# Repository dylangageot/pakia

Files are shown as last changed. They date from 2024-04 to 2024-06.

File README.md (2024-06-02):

# PS/2 to Amiga Keyboard Interface Adapter (PAKIA)

Standalone Amiga keyboards are more than ever difficult to find, especially due to the increased perceived value of Amiga computers and peripherals on the second-hand market.

Unfortunately, the keyboard interface used by Commodore is proprietary, see the [Amiga keyboard interface documentation](http://amigadev.elowar.com/read/ADCD_2.1/Hardware_Manual_guide/node0172.html).
Even though it uses the same 5-pin DIN 41524 connector as IBM AT keyboards, the keyboard interface is still different and therefore not compatible with any easy-to-find PC-compatible keyboards.

PAKIA is yet another adapter circuit, taking a PS/2 keyboard interface in input, and translating it into the Amiga keyboard interface in output.

<p align="center">
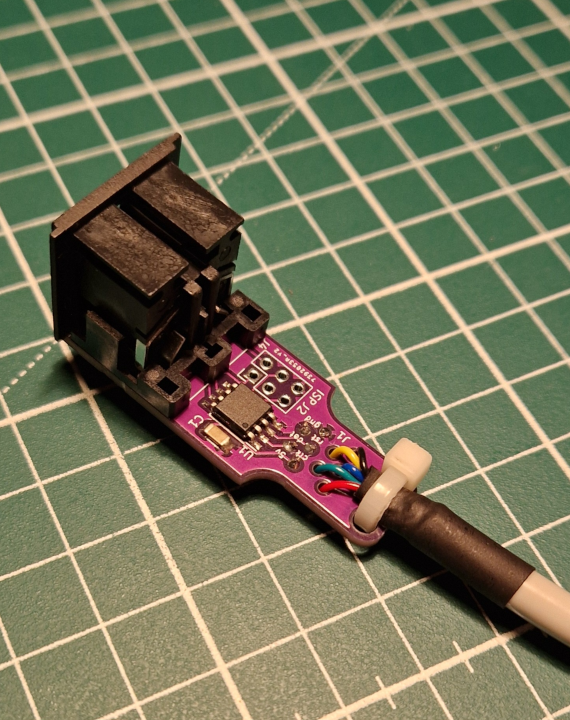
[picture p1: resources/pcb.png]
  
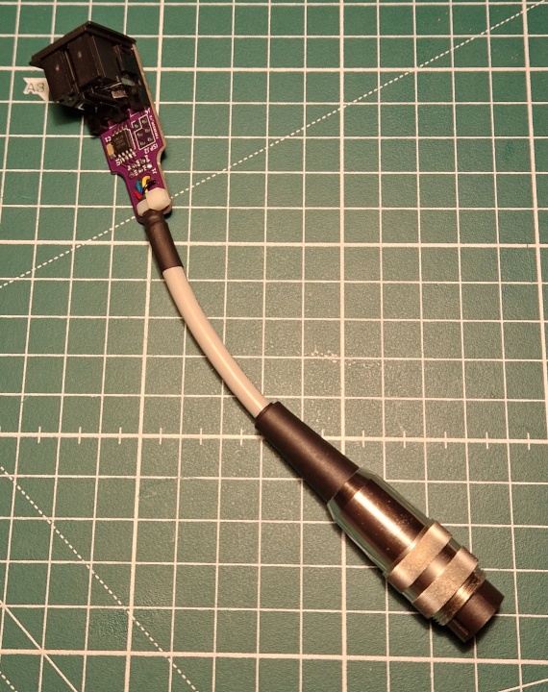
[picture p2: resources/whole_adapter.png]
  
</p>

## Features

- Convert PS/2 scancode to Amiga scancode,
- Handle lost synchronization and corresponding recovery,
- Handle the reset combo (Ctrl + Left Amiga + Right Amiga) with the two reset warnings,
- Interact with PS/2 keyboard to set Caps Lock LED,
- Use the [Menu](https://en.wikipedia.org/wiki/Menu_key) modifier key to type a key that has been absorbed by a larger key on the PS/2 keyboard but is present on an Amiga keyboard,
- PCB with: 
    - on-board DIN socket for AT and PS/2 keyboards connection, with the later usable with a mini-DIN to DIN adapter cable,
    - strain relief for wire coming from the Amiga. 

## Under the hood

Despite being different, both PS/2 and Amiga keyboard interfaces share similarities: they use the same KDAT and KCLK signal pair.
In either case, the keyboard is responsible for generating the clock and preparing 8 data bits to be read on the KDAT signal a falling or rising edge of the KCLK signal.

Leveraging multiple timers and interrupt service routines, an ATtiny85 captures frames sent out from an input PS/2 keyboard, interprets them, and then converts them to the Amiga keyboard interface using a look-up table written in Flash memory.

In contrast to other solutions, signal timings for the Amiga keyboard interface are driven by discrete time events instead of being driven by blocking delays.
One hardware timer generates periodic interrupt requests that once the corresponding ISR runs, the signal is taught to evolve its state through a software-based finite state machine, hence changing pins levels for both KDAT and KCLK.

This asynchronous philosophy makes it possible to incorporate this piece of software in a busier system, without introducing blocking delay when Amiga commands are being sent, minus interrupt service routines execution time of course.

You might think that this is overengineering and that other solutions got it right enough by using blocking delays to handle their signal timings, and you are probably right!
The solution I have implemented was way more stimulating for me to develop, so here we are!

The binary currently weighs 3.2KB, in that regard, one could choose to use an ATtiny45 instead of an ATtiny85, it might be enough even in case of additional features coming in future updates.

The project uses C++ mainly to benefit from namespaces.

## Build and deploy

> [!WARNING]
> The build system is only available on Linux.

> **Required:** `avr-gcc` and `avrdude`, respectively 5.4.0 and 6.3-20171130 on my setup.

1. Specify the programmer to use with `avrdude` in the Makefile, with the variable `PROGRAMMER`,
2. Build with `make`,
3. Deploy with `make flash` while your programmer is wired to the ISP connector on the PCB.

## Edit the translation map

The lookup table to convert PS/2 scancode to Amiga ones is hard-coded in `src/translation_map.hh`.
A tool called `translation-map-generator` can be built from the `tools` directory.
By modifying the source code, one can generate other hard-coded LUT from a readable code:

```bash
(cd tools && make)
tools/translation-map-generator > src/translation_map.hh
```

##  Schematic and PCB

The schematic and PCB were drawn in KiCAD. The project is available in the `hardware` directory.

## Other solutions

> "yet another adapter circuit", is there are other adapter circuits?

Yes, there are other adapter circuits! 

I have started this project blindly, without searching if anyone made one before.
Frankly, it was appealing to my eye, so why not!
I have found documentation on both keyboard interfaces and started developing a proof of concept on an Arduino Uno board, based on an ATmega328p.

I have discovered many of them once I had finished the prototype for PAKIA and wanted to design a PCB for it, with eventually a lighter microcontroller than the ATmega328p.
Here is a list of related open-source projects and their respective solutions:

- [AKAB](https://gitlab.com/hkzlab-retrocomputing/AKAB_Reloaded) by [hkzlabnet](http://mercatopo-en.blogspot.com/)
    - uses an ATmega328p as a microcontroller (32KB Flash, 2KB SRAM),
    - leverages a pure AVR development environment,
    - provides a KiCAD project with schematic and PCB design,
    - PCB based on both through-hole DIP-28 ATmega328p and mini-DIN socket,
    - see a photo of the adapter board in [the dedicated blog article](http://mercatopo-en.blogspot.com/2013/11/first-prototype-of-akab-amiga-keyboard.html),
    - implements Amiga Ctrl-Amiga-Amiga reset combo keys, 
- [PS2toAmiga](https://github.com/Jartza/PS2toAmiga) by [Jartza](https://github.com/Jartza)
    - uses an ATtiny85 as a microcontroller (8K Flash, 512B SRAM),
    - leverages the Arduino development environment,
    - provides a KiCAD project with schematic and PCB design,
    - PCB based on SMD SOIC8 ATtiny85 and pads to solder wires on for both PS/2 and Amiga keyboard wires,
    - designed to fit inside a keyboard,
    - see photos of the adapter board on the repository README.md,
    - implements Amiga Ctrl-Amiga-Amiga reset combo keys, 
    - two different keyboard layouts selectable from the *Scroll Lock* key.

There is also the [Lyra 3](http://wiki.icomp.de/wiki/Lyra_3) adapter sold by Individual Computers.
This one is very complete feature-wise, but I did not want to buy one as I thought that it would spoil my pleasure of developing my own, I'm sure you get it, right?

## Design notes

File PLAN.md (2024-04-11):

# Plan

***Resources:***
- [Arduino pinout](https://docs.arduino.cc/resources/pinouts/A000066-full-pinout.pdf)

# 1. Implement IBM AT PS/2 protocol

> The PS/2 keyboard port is electrically and logically identical to the IBM AT keyboard port, differing only in the type of electrical connector used. - [Wikipedia](https://en.wikipedia.org/wiki/PS/2_port)

The nature of the protocol is synchronous master/slave bidirectional, with favor from the keyboard to the host.
Data and clock signals are both open-collector controlled on each side.
The keyboard generates the clock signal, even when the host is sending data to the device.
The host controls the directions by pulling the clock line to LOW.
When the clock is set to LOW from the host, the keyboard is inhibited.
The keyboard should be able to see that and will stop transmitting data.

***Pinout of female DIN 5-pin:***
```
     .---. .---.
    /    |_|    \
   /             \    1: Clock
  | 3           1 |   2: Data
  | o  5     4  o |   3: Reset(XT Type-1)
   \  o   2   o  /    4: GND
    \     o     /     5: 5V
     `--.___,--'
```

***Sources:***
- https://github.com/tmk/tmk_keyboard/wiki/IBM-PC-AT-Keyboard-Protocol
- https://en.wikipedia.org/wiki/PS/2_port

## Implementation ideas

- Use interrupt on clock line to receive data
- When the clock is being controlled by the keyboard, use the corresponding pin in input mode
- When the clock has to be pulled to the low state by the host, use the corresponding pin in output with LOW state

## Todo

- ✅ First research on IBM protocol
- ✅ Cut the wire in half, solder sub-wires to the female DIN connector
- ✅ Solder HE14 header pin on the other side
- ✅ Acquire through an interrupt scan code from the keyboard
- ⬛ Communicate with the keyboard (set Num Lock, Caps Lock...)

## Correspondance scan code set 2

```
        ,-----------------------------------------------.
        |F13|F14|F15|F16|F17|F18|F19|F20|F21|F22|F23|F24|
,---.   |-----------------------------------------------|     ,-----------.     ,-----------.
|Esc|   |F1 |F2 |F3 |F4 |F5 |F6 |F7 |F8 |F9 |F10|F11|F12|     |PrS|ScL|Pau|     |VDn|VUp|Mut|
`---'   `-----------------------------------------------'     `-----------'     `-----------'
,-----------------------------------------------------------. ,-----------. ,---------------.
|  `|  1|  2|  3|  4|  5|  6|  7|  8|  9|  0|  -|  =|JPY|Bsp| |Ins|Hom|PgU| |NmL|  /|  *|  -|
|-----------------------------------------------------------| |-----------| |---------------|
|Tab  |  Q|  W|  E|  R|  T|  Y|  U|  I|  O|  P|  [|  ]|  \  | |Del|End|PgD| |  7|  8|  9|  +|
|-----------------------------------------------------------| `-----------' |---------------|
|CapsL |  A|  S|  D|  F|  G|  H|  J|  K|  L|  ;|  '|  #|Entr|               |  4|  5|  6|KP,|
|-----------------------------------------------------------|     ,---.     |---------------|
|Shft|  <|  Z|  X|  C|  V|  B|  N|  M|  ,|  .|  /| RO|Shift |     |Up |     |  1|  2|  3|Ent|
|-----------------------------------------------------------| ,-----------. |---------------|
|Ctl|Gui|Alt|MHEN|     Space      |HENK|KANA|Alt|Gui|App|Ctl| |Lef|Dow|Rig| |  #|  0|  .|KP=|
`-----------------------------------------------------------' `-----------' `---------------'

        ,-----------------------------------------------.
        | 08| 10| 18| 20| 28| 30| 38| 40| 48| 50| 57| 5F|
,---.   |-----------------------------------------------|     ,-----------.     ,-----------.
| 76|   | 05| 06| 04| 0C| 03| 0B| 83| 0A| 01| 09| 78| 07|     |+7C| 7E|+77|     |*21|*32|*23|
`---'   `-----------------------------------------------'     `-----------'     `-----------'
,-----------------------------------------------------------. ,-----------. ,---------------.
| 0E| 16| 1E| 26| 25| 2E| 36| 3D| 3E| 46| 45| 4E| 55| 6A| 66| |*70|*6C|*7D| | 77|*4A| 7C| 7B|
|-----------------------------------------------------------| |-----------| |---------------|
| 0D  | 15| 1D| 24| 2D| 2C| 35| 3C| 43| 44| 4D| 54| 5B|  5D | |*71|*69|*7A| | 6C| 75| 7D| 79|
|-----------------------------------------------------------| `-----------' |---------------|
| 58   | 1C| 1B| 23| 2B| 34| 33| 3B| 42| 4B| 4C| 52|^5D| 5A |               | 6B| 73| 74| 6D|
|-----------------------------------------------------------|     ,---.     |---------------|
| 12 | 61| 1A| 22| 21| 2A| 32| 31| 3A| 41| 49| 4A| 51|  59  |     |*75|     | 69| 72| 7A|*5A|
|-----------------------------------------------------------| ,-----------. |---------------|
| 14|*1F| 11| 67 |     29         | 64 | 13 |*11|*27|*2F|*14| |*6B|*72|*74| | 68| 70| 71| 63|
`-----------------------------------------------------------' `-----------' `---------------'
*: E0-prefixed codes
+7C: E0 12 E0 7C
+77: E1 14 77 E1 F0 14 F0 77
^: ISO hash key uses identical scancode 5D to US backslash.
51, 63, 68, 6A, 6D: Hidden keys in IBM model M [6]
```

# 2. Implement Amiga keyboard protocol

KCLK is managed by keyboard.
KDATA is managed by both.
Active low signal levels.
Open collector setup.

***Sources:***
- http://amigadev.elowar.com/read/ADCD_2.1/Hardware_Manual_guide/node0172.html

## Implementation idea

- Generate a discrete periodic interrupt by using a timer [Clear Time on Capture Match](https://ww1.microchip.com/downloads/en/DeviceDoc/Atmel-7810-Automotive-Microcontrollers-ATmega328P_Datasheet.pdf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) feature, powering the bit-banging timing for the Amiga protocol.
Wait for acknowledgment from the Amiga by setting up an interrupt on the falling or rising edge of the KDATA line.

## Todo

- ✅ Use timer and interrupt to implement CLOCK and DATA positioning for Amiga protocol
- ✅ Handle ACK from device on keyboard side (Arduino)
- ✅ Translate scancode to Amiga scancodes
- ✅ Move to PCINT for ack detection
- ✅ Find an appropriate MCU for the final product
        - does using a PCINT instead of INT0 for Amiga ack detection would suffice?
         in this case, we could use a cool ATTiny!
         ATTiny85 seems low on SRAM...
- ✅ Make a PCB
- ⬛ Design revision 2 using a dedicated DIN socket on the PCB, 
        - ✅ Add footprint for DIN 5PIN
        - ⬛ Add pad for wire soldering of amiga cable without hole
        - ⬛ Add dedicated ISP AVR socket
        - ⬛ Make hole for a 3D model case

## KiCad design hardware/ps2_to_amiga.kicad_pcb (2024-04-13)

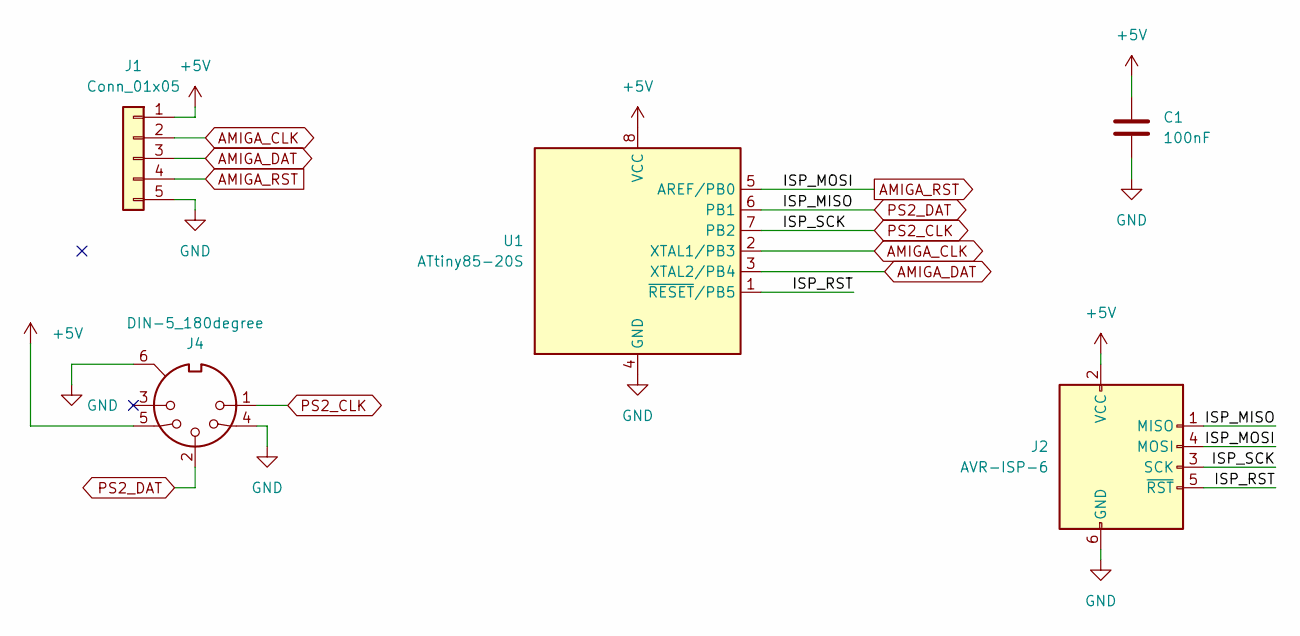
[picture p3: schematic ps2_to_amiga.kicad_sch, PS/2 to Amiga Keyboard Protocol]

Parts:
C1: 100nF; C_1206_3216Metric_Pad1.33x1.80mm_HandSolder
J1: Conn_01x05; AMIGA_KB_PADS
J2: AVR-ISP-6; PinHeader_2x03_P2.54mm_Vertical
J4: DIN-5_180degree; DIN_5PIN_180d_Female
U1: ATtiny85-20S; SOIC-8W_5.3x5.3mm_P1.27mm

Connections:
+5V: C1.1, J1.1, J2.2 (VCC), J4.5, U1.8 (VCC)
/ISP_RST: J2.5 (~RST), U1.1 (~RESET/PB5)
AMIGA_CLK: J1.2, U1.2 (XTAL1/PB3)
AMIGA_DAT: J1.3, U1.3 (XTAL2/PB4)
AMIGA_RST: J1.4, J2.4 (MOSI), U1.5 (AREF/PB0)
GND: C1.2, J1.5, J2.6 (GND), J4.4, J4.6, U1.4 (GND)
PS2_CLK: J2.3 (SCK), J4.1, U1.7 (PB2)
PS2_DAT: J2.1 (MISO), J4.2, U1.6 (PB1)

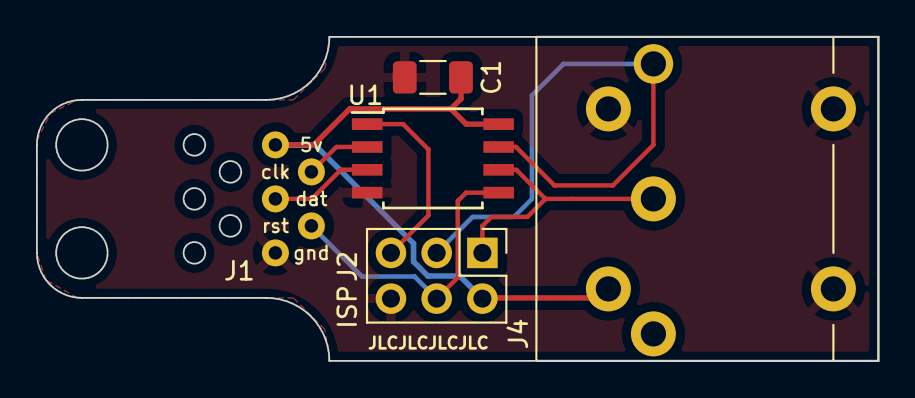
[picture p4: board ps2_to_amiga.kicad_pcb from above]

Board: 2 copper layers, 46.8 x 18.0 mm, 5 parts (0 on the bottom side), 8 nets.

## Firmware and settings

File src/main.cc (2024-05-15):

#include <avr/interrupt.h>
#include <avr/io.h>
#include <avr/wdt.h>

#include "amiga.hh"
#include "ps2.hh"
#include "scancodes.hh"
#include "translation_map.hh"

enum {
    COMBO_PRESSED = 7,
    RESET_REQUEST_SENT = 1 << 3,
    COMBO_RELEASED = 1 << 4
};

void setup() {
    MCUCR &= ~(1 << PUD);  // Enable pull-up resistors.
    MCUSR &= ~(1 << WDRF); // Reset Watchdog reset flag.
    wdt_disable();
    sei();
    ps2::begin();
    amiga::begin();
    ps2::send(ps2::command::RESET);
}

int main() {
    namespace scps2 = scancodes::ps2;
    namespace scami = scancodes::amiga;
    ps2::receiver receiver;
    ps2::event event;
    uint8_t last_scancode = 0;
    uint8_t reset_combo = 0;
    bool caps_lock = false;
    bool alt_num_pad = false;
    setup();
    while (1) {
        if (receiver.consume(event)) {
            uint8_t reset_key =
                (event.scancode == scps2::LEFT_CTRL ? 1 : 0) |
                (event.scancode == scps2::extended::LEFT_OS ? 2 : 0) |
                (event.scancode == scps2::extended::RIGHT_OS ? 4 : 0);

            // Detect reset combo (Ctrl + Left Amiga + Right Amiga).
            if (reset_key && !(reset_combo & COMBO_RELEASED)) {
                if (event.kind == ps2::event::PRESSED &&
                    !(reset_combo & RESET_REQUEST_SENT)) {
                    reset_combo |= reset_key;
                    if ((reset_combo & COMBO_PRESSED) == COMBO_PRESSED) {
                        amiga::hold_reset();
                        reset_combo |= RESET_REQUEST_SENT;
                    }
                } else if (event.kind == ps2::event::RELEASED) {
                    reset_combo &= ~reset_key;
                    if (reset_combo & RESET_REQUEST_SENT) {
                        amiga::release_reset();
                        reset_combo |= COMBO_RELEASED;
                    }
                }
            }

            if (amiga::is_ready()) {
                uint8_t amiga_scancode =
                    pgm_read_byte_near(ps2_to_amiga_scancode + event.scancode);

                if ((event.kind == ps2::event::PRESSED) &&
                    (event.scancode == last_scancode)) {
                    continue;
                }

                // Detect alternative key (Menu).
                alt_num_pad = event.scancode == scps2::extended::MENU
                                  ? event.kind == ps2::event::PRESSED
                                  : alt_num_pad;

                // Drop any unknown key.
                // Past this point, any unknown scancode on amiga side cannot be
                // used.
                if (amiga_scancode == 0xFF) {
                    continue;
                }

                // If + key is actually a - due to the alternative
                // keypad function.
                amiga_scancode =
                    alt_num_pad && (amiga_scancode == scami::NUM_PLUS)
                        ? scami::NUM_MINUS
                        : amiga_scancode;

                // Send key with its type (key up or key down).
                if (event.kind == ps2::event::PRESSED) {
                    last_scancode = event.scancode;
                    if (event.scancode != scps2::CAPS_LOCK) {
                        amiga::send(amiga_scancode);
                    } else {
                        caps_lock = !caps_lock;
                        amiga::send(
                            amiga_scancode |
                            (caps_lock ? amiga::KEY_DOWN : amiga::KEY_UP));
                        ps2::send(ps2::command::SET_RESET_LEDS,
                                  caps_lock ? ps2::leds::CAPS_LOCK : 0);
                    }
                } else if (event.kind == ps2::event::RELEASED) {
                    last_scancode =
                        event.scancode == last_scancode ? 0 : last_scancode;
                    if (event.scancode != scps2::CAPS_LOCK) {
                        amiga::send(amiga_scancode | amiga::KEY_UP);
                    }
                }
            }
        }
    }
}

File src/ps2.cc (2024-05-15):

#include <avr/interrupt.h>
#include <avr/io.h>

#include "circular_buffer.hh"
#include "pins.hh"
#include "ps2.hh"

namespace ps2 {

    enum direction { RECEIVING = 0, SENDING };

    struct circular_buffer<uint8_t, 8> scancodes;

    void (*state)();
    direction direction;
    uint8_t data;
    uint8_t counter;
    uint8_t cmd[2];
    bool has_arg;
    uint8_t byte_counter;

    static inline void set_pins_pull_up() {
        DDRB &= ~(pins::ps2::CLK | pins::ps2::DAT);
        PORTB |= pins::ps2::CLK | pins::ps2::DAT;
    }

    static inline void set_clk_pull_up() {
        DDRB &= ~(pins::ps2::CLK);
        PORTB |= pins::ps2::CLK;
    }

    static inline void set_clk_low() {
        PORTB &= ~pins::ps2::CLK;
        DDRB |= pins::ps2::CLK;
    }

    static inline void set_dat_pull_up() {
        DDRB &= ~(pins::ps2::DAT);
        PORTB |= pins::ps2::DAT;
    }

    static inline void set_dat_low() {
        PORTB &= ~pins::ps2::DAT;
        DDRB |= pins::ps2::DAT;
    }

    static inline void setup_clk_detection_int_as_falling() {
        MCUCR = (MCUCR & ~((1 << ISC01) | (1 << ISC00))) | (1 << ISC01);
    }

    static inline void setup_clk_dectection_int_as_rising() {
        MCUCR = (MCUCR & ~((1 << ISC01) | (1 << ISC00))) | (1 << ISC01) |
                (1 << ISC00);
    };

    static inline void enable_clk_detection_int() {
        GIFR |= (1 << INTF0);
        GIMSK |= (1 << INT0);
    }

    static inline void disable_clk_detection_int() { GIMSK &= ~(1 << INT0); }

    static inline void setup_timer_for_inhibition() {
        TCCR0A = (1 << WGM01);
        TCCR0B = (1 << CS02) | (1 << CS00);
        TCNT0 = 155;
    }

    static inline void setup_timer_for_rts() {
        TCCR0A = (1 << WGM01);
        TCCR0B = (1 << CS01);
        TCNT0 = 101;
    }

    static inline void enable_timer_int() {
        TIFR |= (1 << OCF0A);
        TIMSK |= (1 << OCIE0A);
    }

    static inline void disable_timer_int() { TIMSK &= ~(1 << OCIE0A); }

    static inline void inhibit(enum direction dir = RECEIVING) {
        direction = dir;
        // lets restore the communications in 20ms, or 100us if request-to-send
        disable_clk_detection_int();
        set_clk_low();
        set_dat_pull_up();
        if (dir == RECEIVING) {
            setup_timer_for_inhibition();
        } else if (dir == SENDING) {
            data = cmd[byte_counter++];
            setup_timer_for_rts();
        }
        enable_timer_int();
    }

    static void wait_for_idle() {
        setup_clk_detection_int_as_falling();
        inhibit(SENDING);
    }

    static void receive_start_bit();

    static void receive_stop_bit() {
        const uint8_t ACK = 0xFA;
        if (!(PINB & pins::ps2::DAT)) {
            return inhibit();
        }
        if (direction == SENDING) {
            if (data == ACK) {
                if (has_arg && byte_counter < 2) {
                    setup_clk_dectection_int_as_rising();
                    state = wait_for_idle;
                } else {
                    direction = RECEIVING;
                    state = receive_start_bit;
                }
            } else if (data == RESEND) {
                byte_counter = 0;
                setup_clk_dectection_int_as_rising();
                state = wait_for_idle;
            } else {
                return inhibit();
            }
        } else if (direction == RECEIVING) {
            if (scancodes.write(data)) {
                state = receive_start_bit;
            } else {
                // if circular data is full, inhibit keyboard scancode reception
                return inhibit();
            }
        }
    }

    static void receive_parity_bit() {
        uint8_t read_parity = (PINB & pins::ps2::DAT) >> pins::ps2::DAT_POS;
        uint8_t computed_parity = data;
        computed_parity ^= computed_parity >> 4;
        computed_parity ^= computed_parity >> 2;
        computed_parity ^= computed_parity >> 1;
        computed_parity = (~computed_parity) & 1;
        if (read_parity != computed_parity) {
            return inhibit();
        }
        counter++;
        state = receive_stop_bit;
    }

    static void receive_data_bits() {
        data |= ((PINB & pins::ps2::DAT) >> pins::ps2::DAT_POS) << counter++;
        state = counter < 8 ? receive_data_bits : receive_parity_bit;
    }

    static void receive_start_bit() {
        if (PINB & pins::ps2::DAT) {
            return inhibit();
        }
        data = 0;
        counter = 0;
        state = receive_data_bits;
    }

    static void receive_ack_bit() {
        if (PINB & pins::ps2::DAT) {
            return inhibit();
        } else {
            state = receive_start_bit;
        }
    }

    static void send_stop_bit() {
        set_dat_pull_up();
        state = receive_ack_bit;
    }

    static void send_parity_bit() {
        uint8_t computed_parity = data;
        computed_parity ^= computed_parity >> 4;
        computed_parity ^= computed_parity >> 2;
        computed_parity ^= computed_parity >> 1;
        computed_parity = (~computed_parity) & 1;
        PORTB =
            (PORTB & ~pins::ps2::DAT) | (computed_parity ? pins::ps2::DAT : 0);
        state = send_stop_bit;
    }

    static void send_data_bits() {
        PORTB = (PORTB & ~pins::ps2::DAT) |
                ((data & (1 << counter++)) ? pins::ps2::DAT : 0);
        state = (counter < 8) ? send_data_bits : send_parity_bit;
    }

    ISR(INT0_vect) { (*state)(); }

    ISR(TIM0_COMPA_vect) {
        if (direction == SENDING) { // Request-To-Send?
            disable_timer_int();
            set_dat_low();
            counter = 0;
            state = send_data_bits;
            set_clk_pull_up();
            enable_clk_detection_int();
        } else if (direction == RECEIVING) {
            disable_timer_int();
            state = receive_start_bit;
            set_pins_pull_up();
            enable_clk_detection_int();
        }
    }

    void begin() {
        state = receive_start_bit;
        direction = RECEIVING;
        has_arg = false;
        set_pins_pull_up();
        setup_clk_detection_int_as_falling();
        enable_clk_detection_int();
    }

    void send(command command, uint8_t cmd_arg) {
        while ((direction == SENDING) || (state != receive_start_bit)) {
        }
        byte_counter = 0;
        cmd[0] = command;
        if ((command == SET_TYPEMATIC_RATE_DELAY) ||
            (command == SET_RESET_LEDS)) {
            cmd[1] = cmd_arg;
            has_arg = true;
        } else {
            has_arg = false;
        }
        return inhibit(SENDING);
    }

    receiver::receiver() { reset(); }

    void receiver::reset() {
        _is_e0_prefixed = false;
        _is_released = false;
        _last_scancode_fed = 0;
    }
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

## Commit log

2024-02-12 Use usual way of handling interrupt
2024-02-12 Swap function pointer for PS/2 interrupt state machine
2024-02-18 Set up interrupt on falling edge to detect acknowledgement
2024-02-18 Add config for timer for resync
2024-02-18 Set flag to 0 for int0 before enabling the interruption
2024-02-19 Successfully printed the first character on the amiga
2024-02-22 Introduce concept of frame_iterator
2024-02-23 Inhibit in case parity or any bit is wrong
    [amiga.cpp, ps2.cpp]
2024-02-25 Add Kicad schematic and pcb
    [ps2_to_amiga.kicad_pcb, ps2_to_amiga.kicad_sch]
2024-03-07 Move Arduino src to src.old
2024-03-10 Switch to C++
2024-03-11 Validate INT0 interrupt
2024-03-11 Remove old Arduino prototype
2024-03-11 Fix PORTB replacement for input reading with PIN
    [amiga.cc, main.cc, ps2.cc]
2024-04-01 Fix many issue with shift+delete, keypad arrangement
    [main.cc]
2024-04-11 Add DIN-5 180deg angle footprint
    [ps2_to_amiga.kicad_pcb, ps2_to_amiga.kicad_sch]
2024-04-13 Design rev2 pcb
    [ps2_to_amiga-B_Cu.gbr, ps2_to_amiga-B_Mask.gbr, ps2_to_amiga-B_Paste.gbr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]
2024-04-28 Fix circular buffer written element
    [amiga.cc]
2024-05-10 Add PCB photo to README.md
2024-05-12 Add prototype function for ps2::send command
2024-05-15 Add support for Caps Lock LED
